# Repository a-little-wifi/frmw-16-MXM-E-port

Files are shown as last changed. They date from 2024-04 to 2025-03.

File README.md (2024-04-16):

# MXM GPU + Dell E-Port expansion card for 16" Framework laptop

This is a board meant to fit in the GPU expansion bay of the 16" Framework laptop. Its primary purpose is to add Dell E-port dock support, but since that requires display outputs, an MXM GPU slot is added as well.

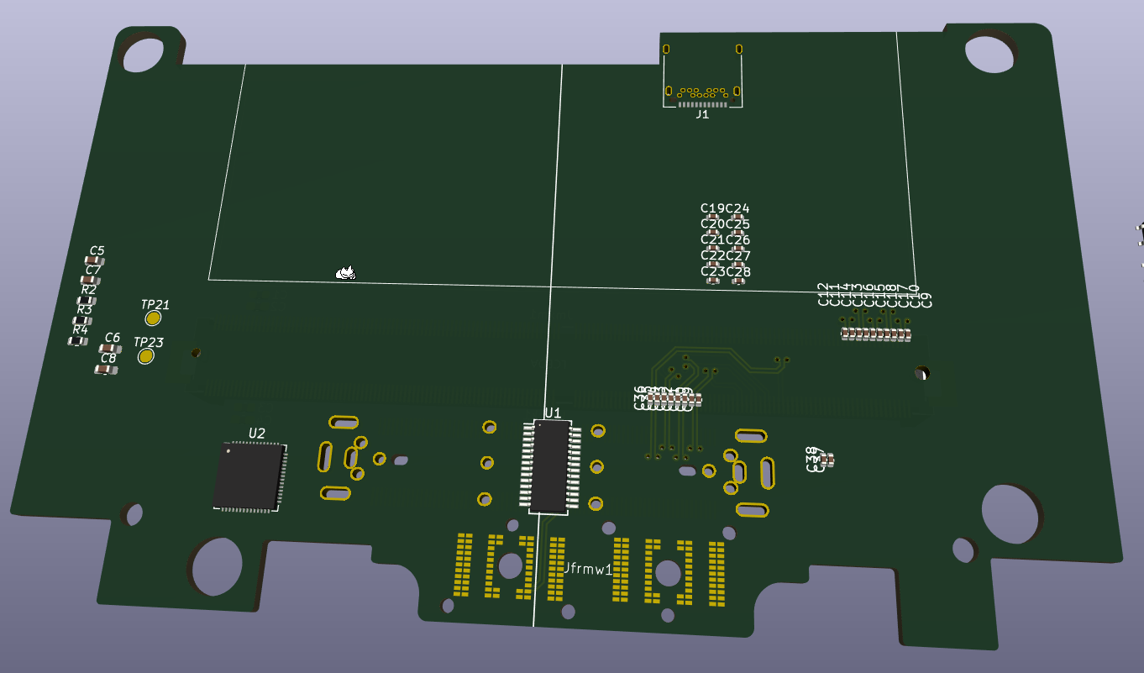
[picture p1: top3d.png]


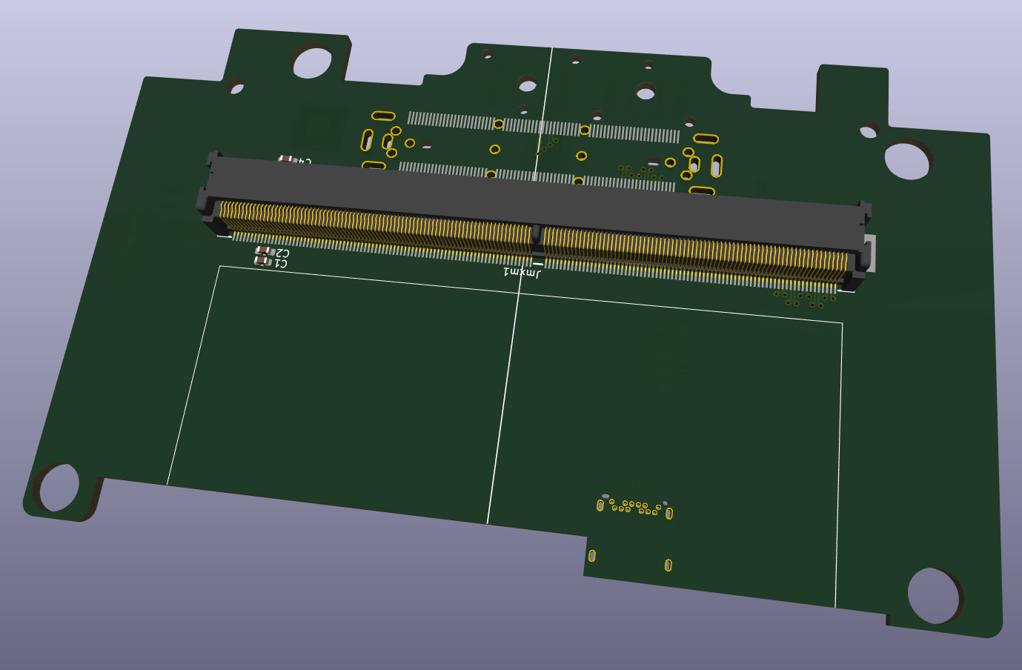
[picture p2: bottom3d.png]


This is a very unfinished project that I started when the 16" Framework laptop was announced, but I probably won't be working on it much anymore since I don't plan on actually buying the laptop. I'm putting it here for anyone who might be interested.

The intent was to use the RP2040 to deal with dock port interfaces such as PS/2, I2S audio, and whatever other control signals it needs to function.

MXM part is based on my work on another project: MXM Immobilizer, a PCIe to MXM adapter.

I've manually created the E-port dock connector footprint from the part datasheet: https://www.mouser.com/pdfdocs/JAEMB-0200-1E_WD2.pdf

Dell's E-port dock uses the JAE WD2 series dock connectors. Part numbers commonly mentioned in applicable schematics are:
* JAE_WD2F144WB5R400 (M4800)
* JAE_WD2F144WB1R300 (E6440)
* JAE_WD2F144WBHR500-DT (E7470)
* JAE_WD2F144WD3 (E4300)
* JAE_WD2F144WD4 (E4200)
* JAE_WD2F144WB3R300 (E4310)
* JAE_WD2F144WB7-DT (E7440)
* JAE_WD2F144WB1 (E6400)

Plus a Foxconn alternative used in some of the last models:
* FOX_QL01723-D265G1-8H (Precision 7510)

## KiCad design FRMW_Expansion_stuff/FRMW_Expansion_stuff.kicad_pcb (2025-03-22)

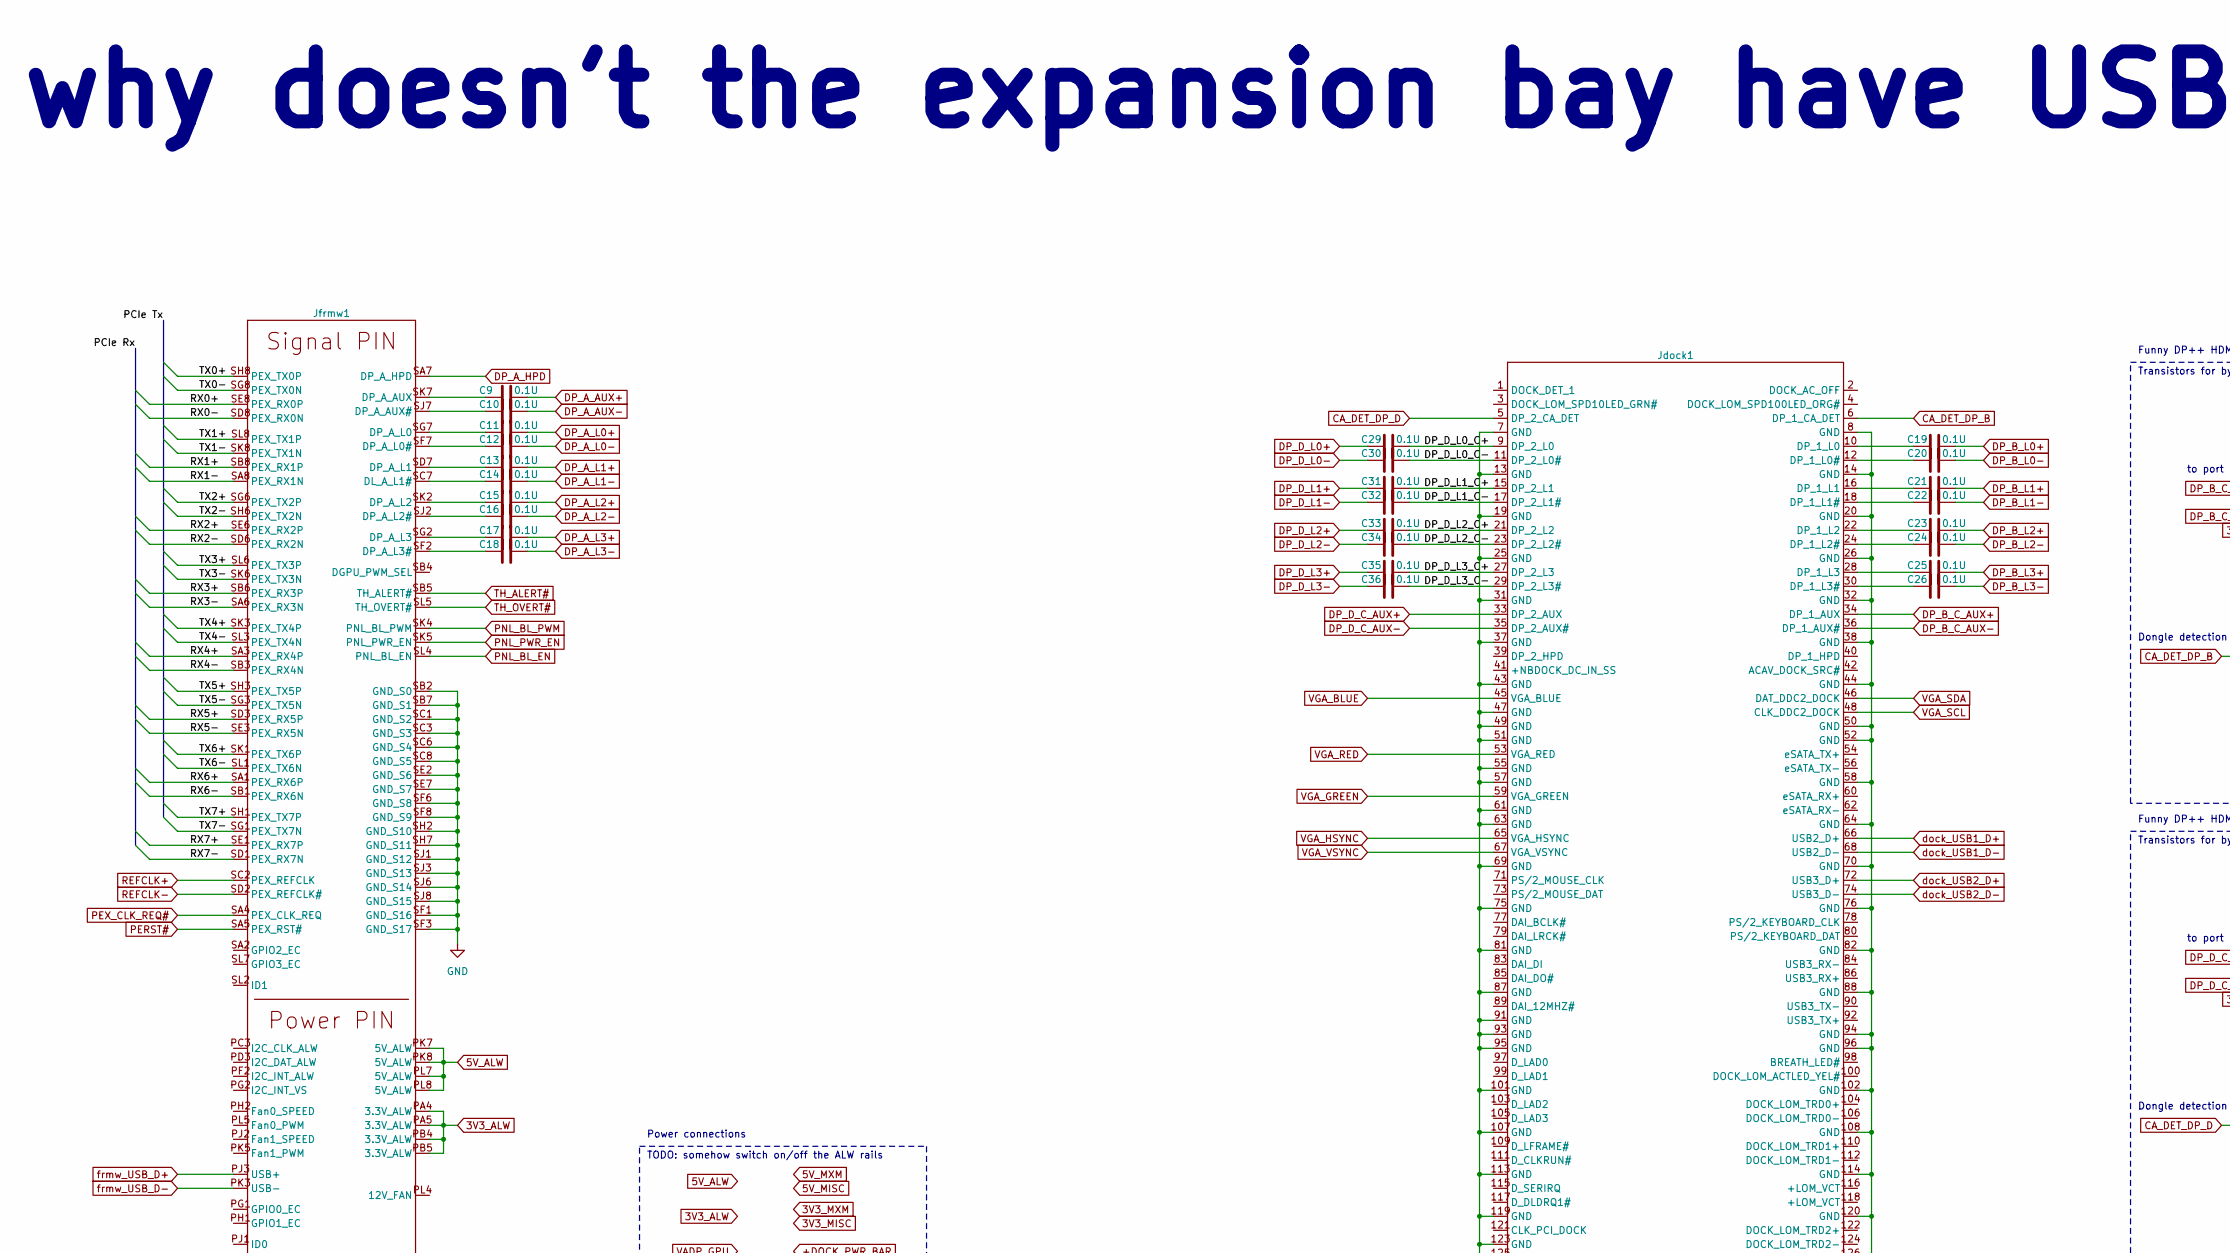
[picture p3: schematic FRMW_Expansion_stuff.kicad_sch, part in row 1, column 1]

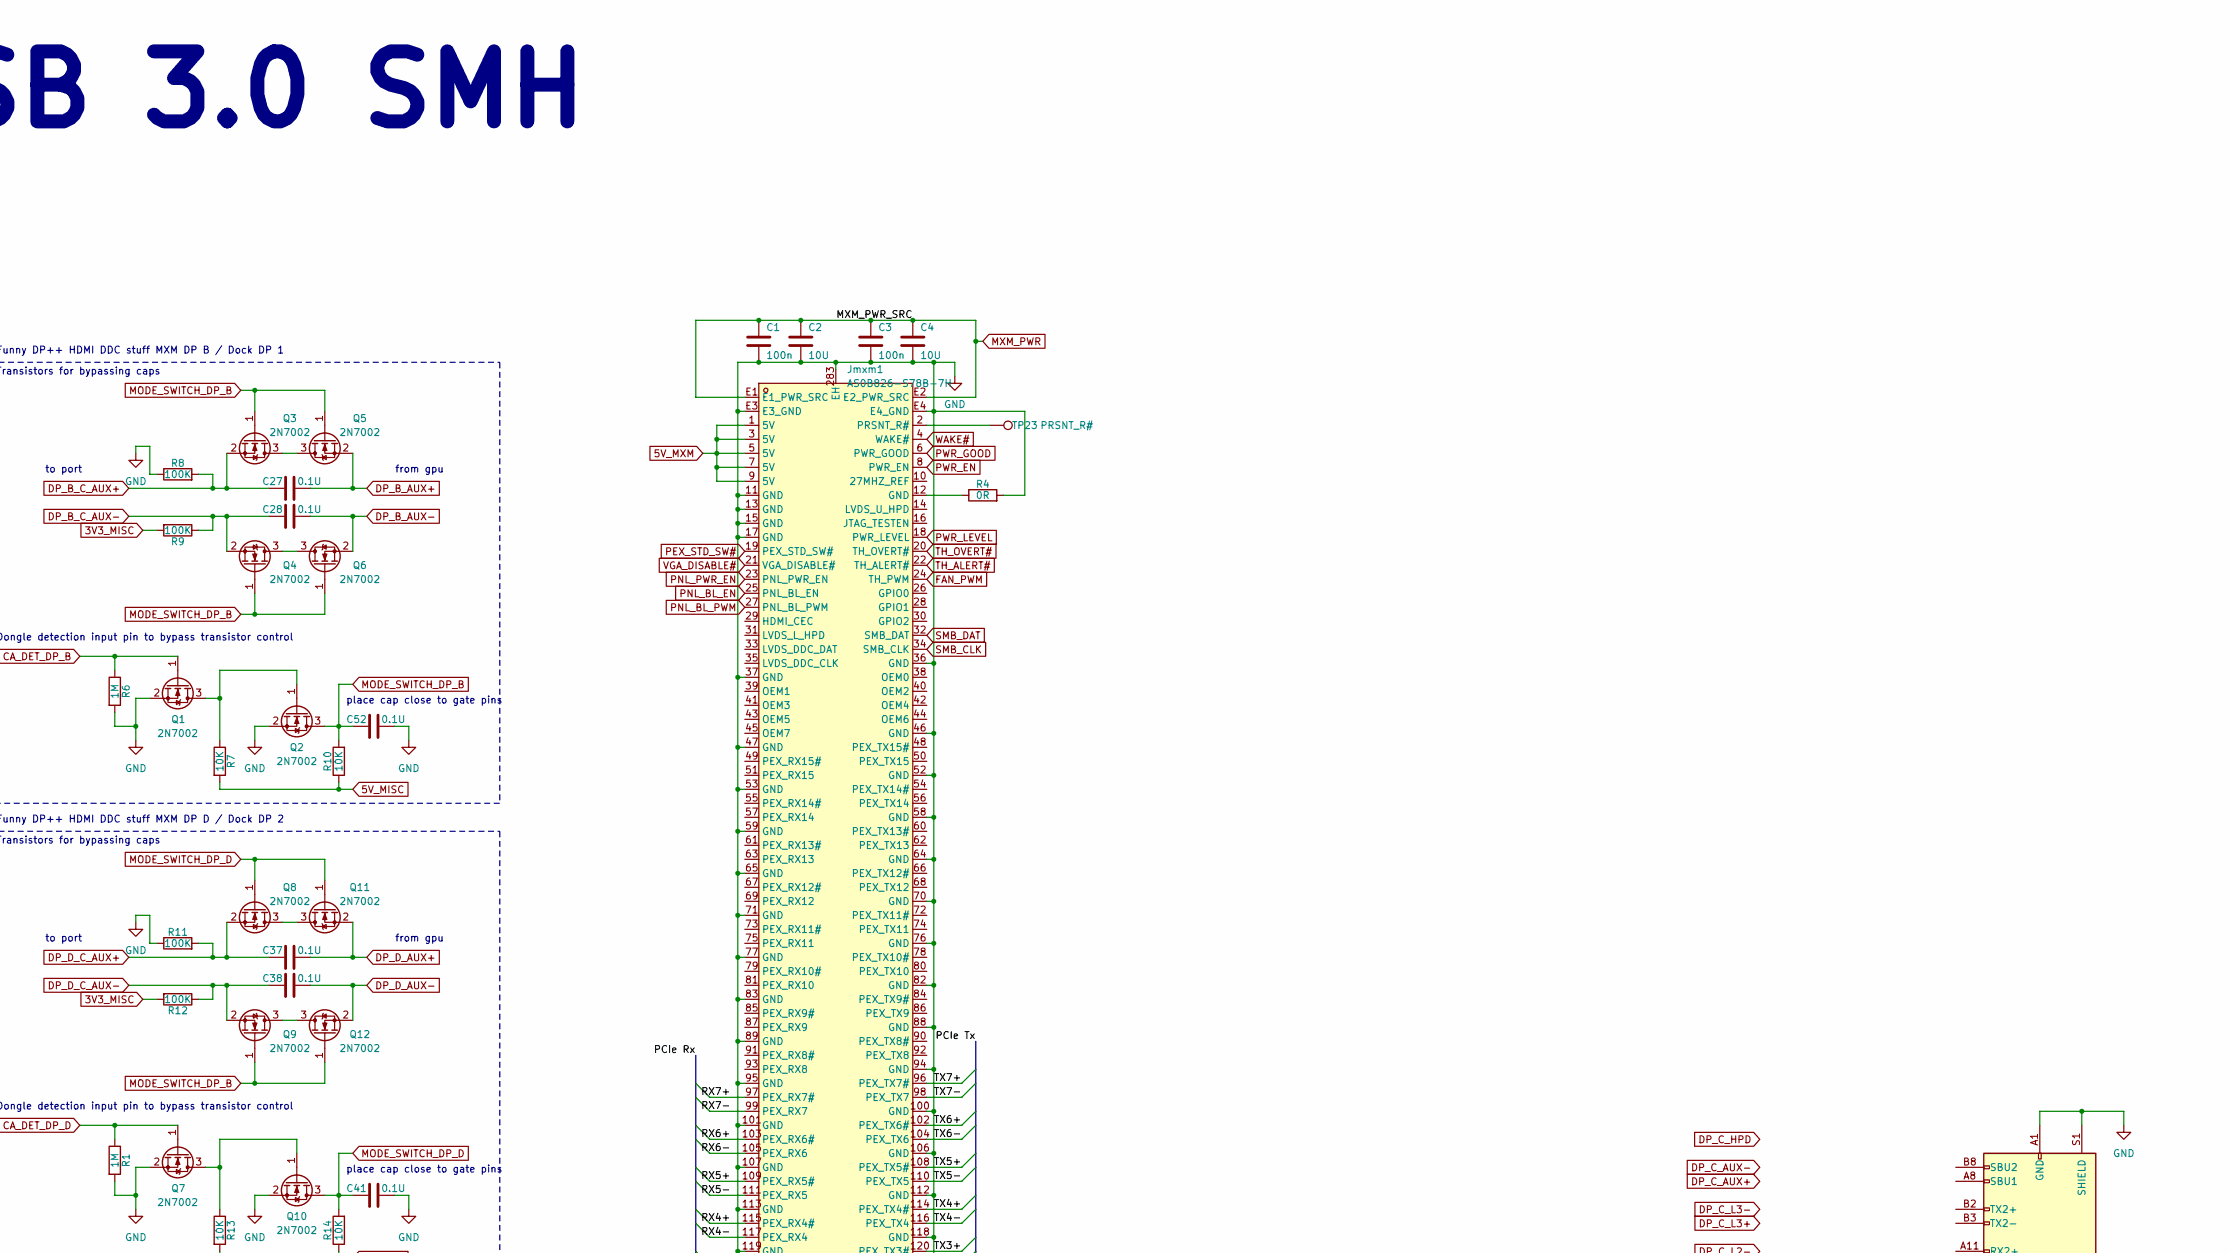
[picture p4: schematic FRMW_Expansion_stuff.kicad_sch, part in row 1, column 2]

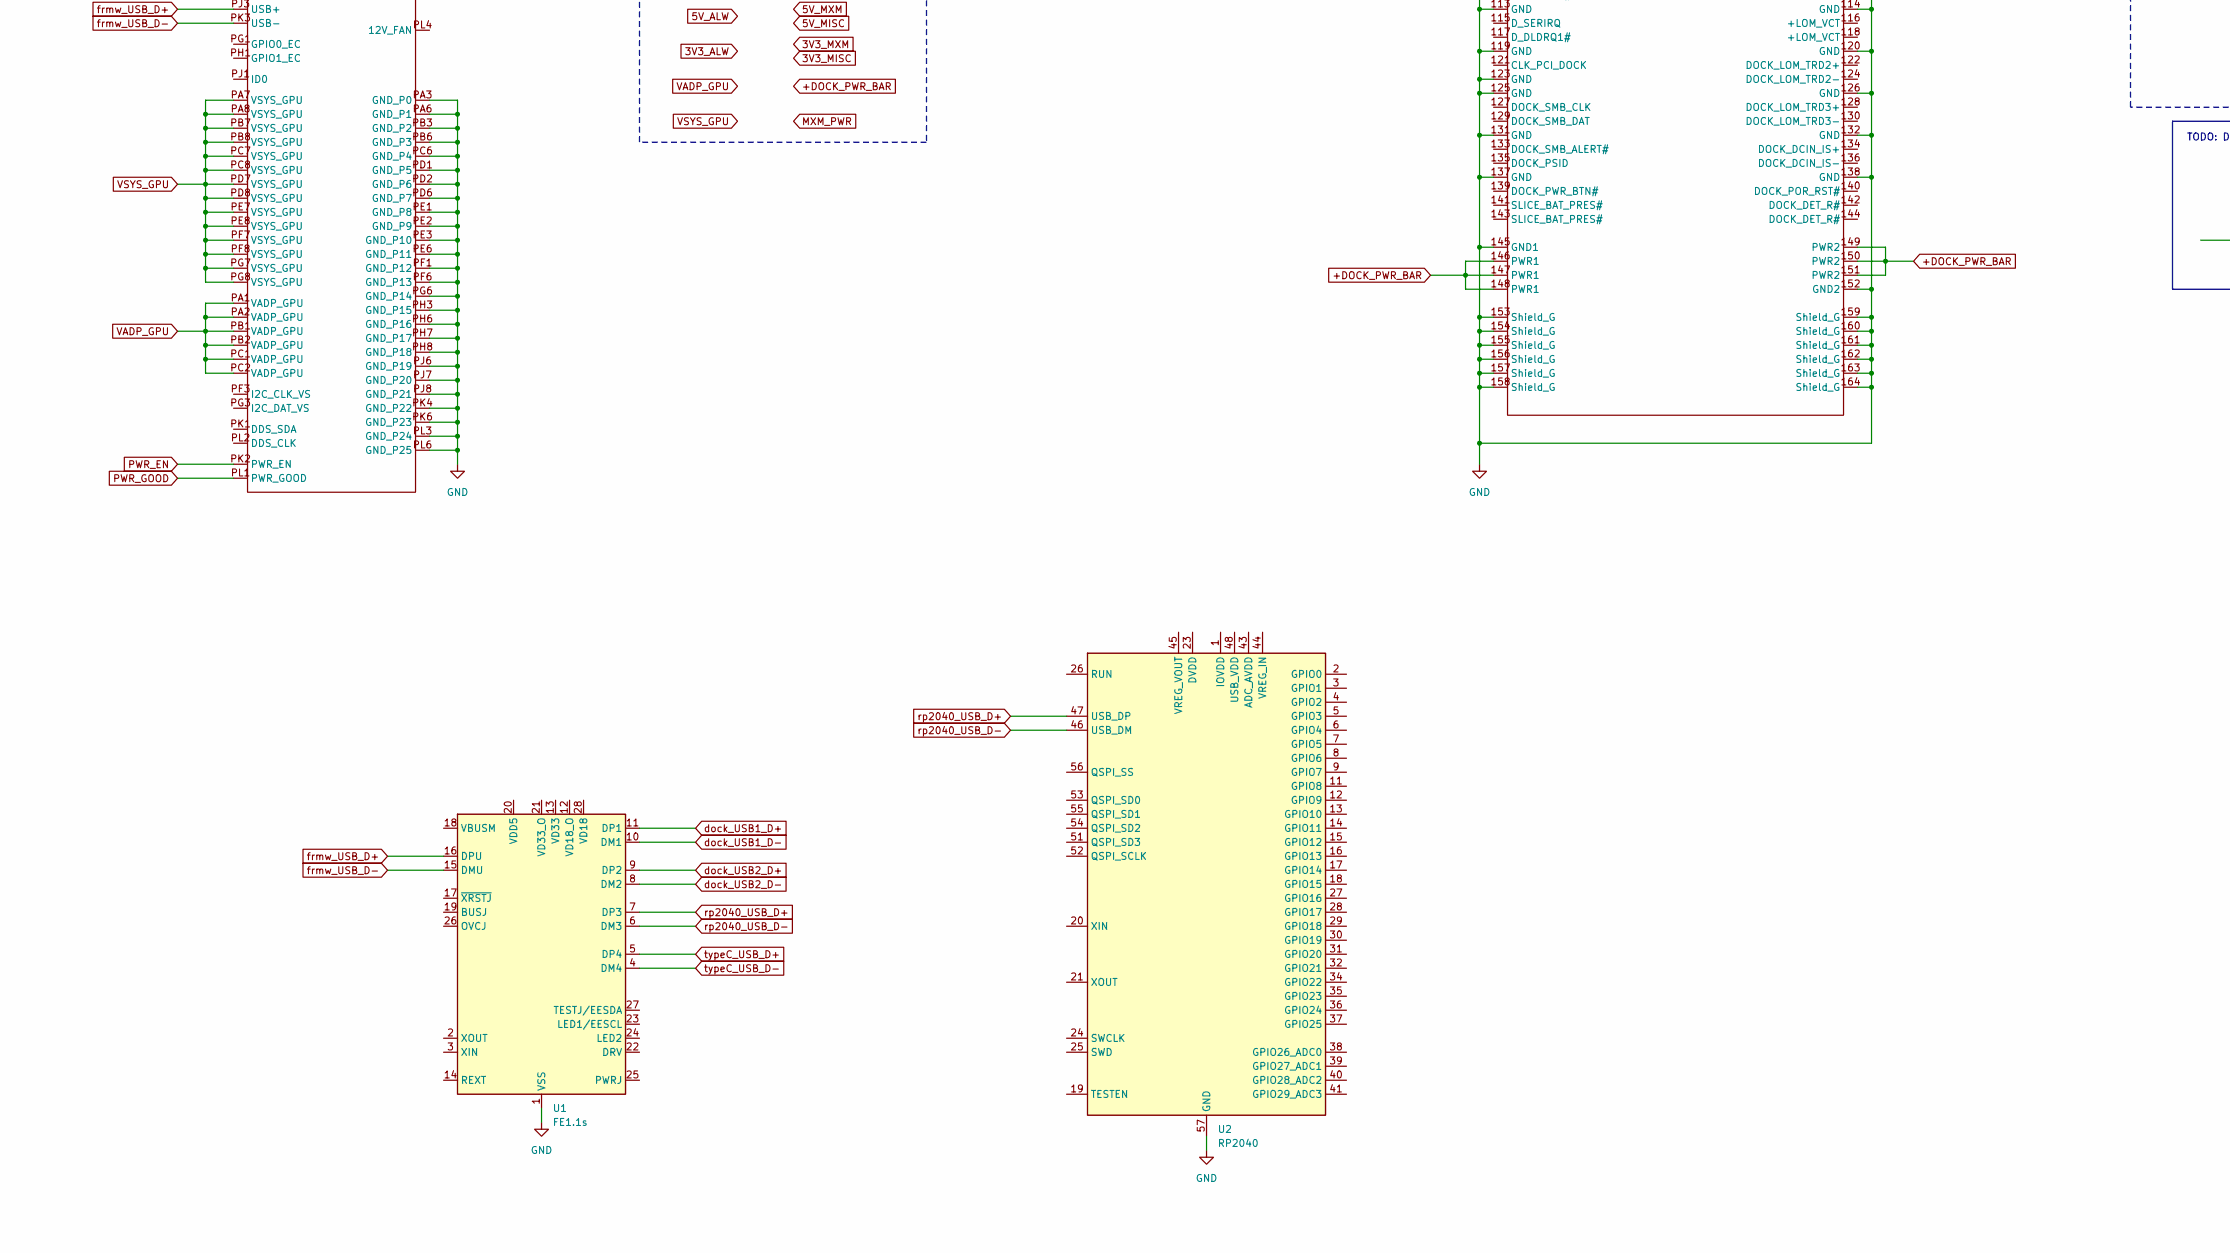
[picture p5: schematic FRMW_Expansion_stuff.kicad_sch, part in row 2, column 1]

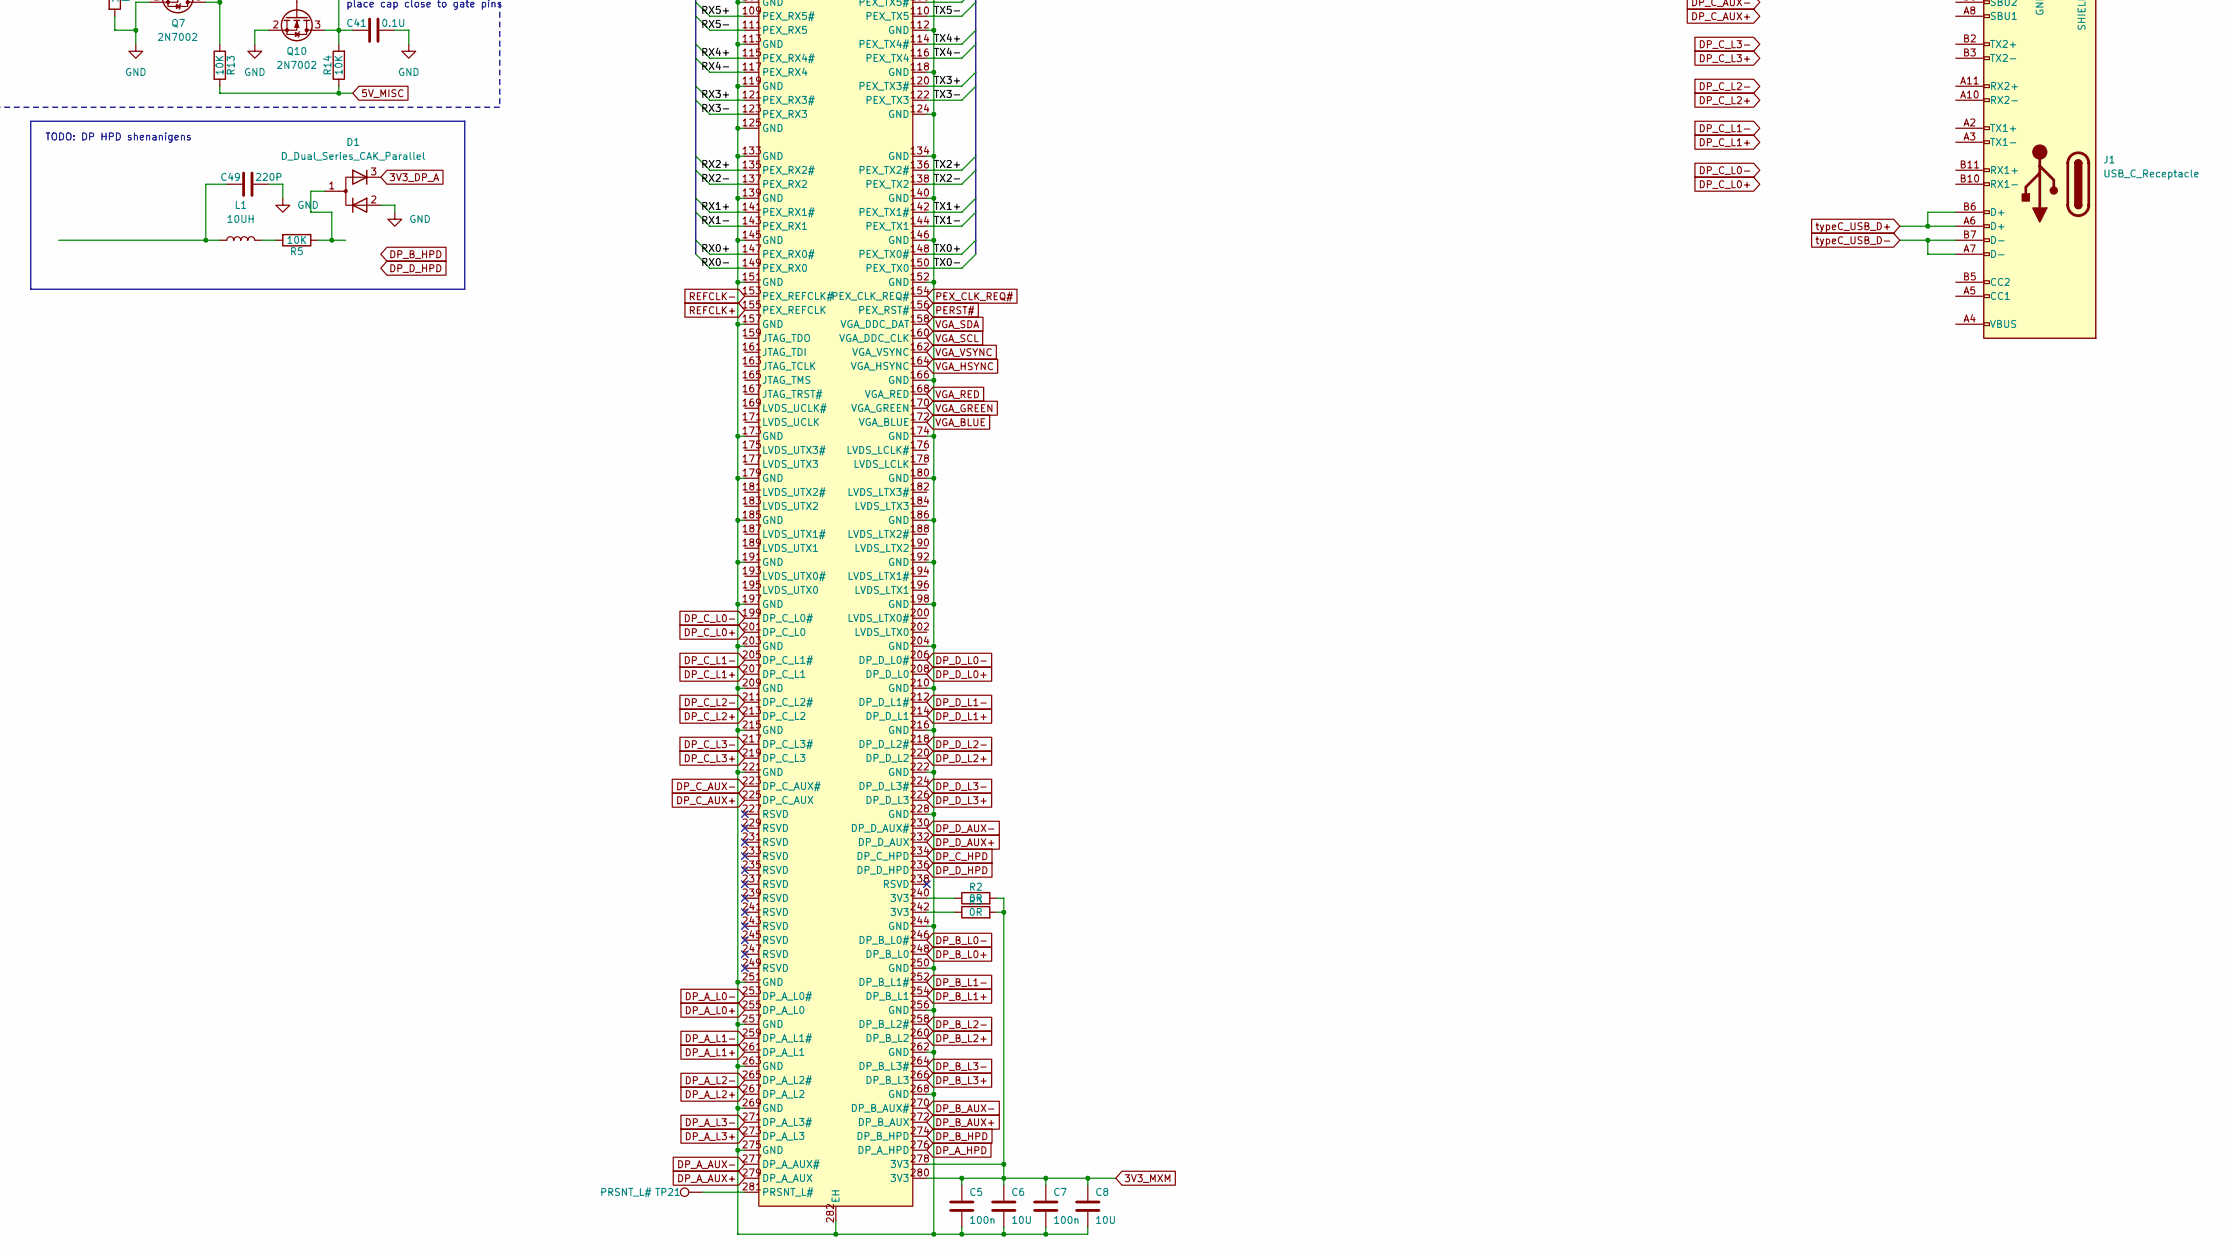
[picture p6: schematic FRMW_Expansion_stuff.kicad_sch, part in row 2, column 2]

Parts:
C1, C3, C5, C7: 100n; C_0603_1608Metric
C2, C4, C6, C8: 10U; C_0603_1608Metric_Pad1.08x0.95mm_HandSolder
C9, C10, C11, C12, C13, C14, C15, C16, C17, C18, C19, C20, C21, C22, C23, C24, C25, C26, C27, C28, C29, C30, C31, C32, C33, C34, C35, C36, C37, C38: 0.1U; C_0402_1005Metric
C41, C52: 0.1U; C_0603_1608Metric
C49: 220P; C_0603_1608Metric
D1: D_Dual_Series_CAK_Parallel; SOT-23
J1: USB_C_Receptacle; USB_C_Receptacle_Amphenol_12401548E4-2A
Jdock1: DellDock
Jfrmw1: Expansion_Bay_FXBeam
Jmxm1: AS0B826-S78B-7H; CONN-SMD_AS0B826-S78B-7H; LCSC Part C426232
L1: 10UH; L_0603_1608Metric_Pad1.05x0.95mm_HandSolder
Q1, Q2, Q3, Q4, Q5, Q6, Q7, Q8, Q9, Q10, Q11, Q12: 2N7002; SOT-23
R1, R6: 1M; R_0603_1608Metric
R2, R3, R4: 0R; R_0603_1608Metric
R5, R7, R10, R13, R14: 10K; R_0603_1608Metric
R8, R9, R11, R12: 100K; R_0603_1608Metric
TP21: PRSNT_L#; TestPoint_Pad_D1.5mm
TP23: PRSNT_R#; TestPoint_Pad_D1.5mm
U1: FE1.1s; SSOP-28_3.9x9.9mm_P0.635mm
U2: RP2040; QFN-56-1EP_7x7mm_P0.4mm_EP3.2x3.2mm

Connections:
3V3_ALW: Jfrmw1.PA4 (3.3V_ALW), Jfrmw1.PA5 (3.3V_ALW), Jfrmw1.PB4 (3.3V_ALW), Jfrmw1.PB5 (3.3V_ALW)
3V3_DP_A: D1.3 (K)
3V3_MISC: R9.2, R12.2
3V3_MXM: C5.1, C6.1, C7.1, C8.1, Jmxm1.278 (3V3), Jmxm1.280 (3V3), R2.2, R3.2
5V_ALW: Jfrmw1.PK7 (5V_ALW), Jfrmw1.PK8 (5V_ALW), Jfrmw1.PL7 (5V_ALW), Jfrmw1.PL8 (5V_ALW)
5V_MISC: R7.2, R10.1, R13.2, R14.1
5V_MXM: Jmxm1.1 (5V), Jmxm1.3 (5V), Jmxm1.5 (5V), Jmxm1.7 (5V), Jmxm1.9 (5V)
+DOCK_PWR_BAR: Jdock1.146 (PWR1), Jdock1.147 (PWR1), Jdock1.148 (PWR1), Jdock1.149 (PWR2), Jdock1.150 (PWR2), Jdock1.151 (PWR2)
/DP_D_L0_C+: C29.1, Jdock1.9 (DP_2_L0)
/DP_D_L0_C-: C30.1, Jdock1.11 (DP_2_L0#)
/DP_D_L1_C+: C31.1, Jdock1.15 (DP_2_L1)
/DP_D_L1_C-: C32.1, Jdock1.17 (DP_2_L1#)
/DP_D_L2_C+: C33.1, Jdock1.21 (DP_2_L2)
/DP_D_L2_C-: C34.1, Jdock1.23 (DP_2_L2#)
/DP_D_L3_C+: C35.1, Jdock1.27 (DP_2_L3)
/DP_D_L3_C-: C36.1, Jdock1.29 (DP_2_L3#)
/RX0+: Jfrmw1.SE8 (PEX_RX0P), Jmxm1.147 (PEX_RX0#)
/RX0-: Jfrmw1.SD8 (PEX_RX0N), Jmxm1.149 (PEX_RX0)
/RX1+: Jfrmw1.SB8 (PEX_RX1P), Jmxm1.141 (PEX_RX1#)
/RX1-: Jfrmw1.SA8 (PEX_RX1N), Jmxm1.143 (PEX_RX1)
/RX2+: Jfrmw1.SE6 (PEX_RX2P), Jmxm1.135 (PEX_RX2#)
/RX2-: Jfrmw1.SD6 (PEX_RX2N), Jmxm1.137 (PEX_RX2)
/RX3+: Jfrmw1.SB6 (PEX_RX3P), Jmxm1.121 (PEX_RX3#)
/RX3-: Jfrmw1.SA6 (PEX_RX3N), Jmxm1.123 (PEX_RX3)
/RX4+: Jfrmw1.SA3 (PEX_RX4P), Jmxm1.115 (PEX_RX4#)
/RX4-: Jfrmw1.SB3 (PEX_RX4N), Jmxm1.117 (PEX_RX4)
/RX5+: Jfrmw1.SD3 (PEX_RX5P), Jmxm1.109 (PEX_RX5#)
/RX5-: Jfrmw1.SE3 (PEX_RX5N), Jmxm1.111 (PEX_RX5)
/RX6+: Jfrmw1.SA1 (PEX_RX6P), Jmxm1.103 (PEX_RX6#)
/RX6-: Jfrmw1.SB1 (PEX_RX6N), Jmxm1.105 (PEX_RX6)
/RX7+: Jfrmw1.SE1 (PEX_RX7P), Jmxm1.97 (PEX_RX7#)
/RX7-: Jfrmw1.SD1 (PEX_RX7N), Jmxm1.99 (PEX_RX7)
/TX0+: Jfrmw1.SH8 (PEX_TX0P), Jmxm1.148 (PEX_TX0#)
/TX0-: Jfrmw1.SG8 (PEX_TX0N), Jmxm1.150 (PEX_TX0)
/TX1+: Jfrmw1.SL8 (PEX_TX1P), Jmxm1.142 (PEX_TX1#)
/TX1-: Jfrmw1.SK8 (PEX_TX1N), Jmxm1.144 (PEX_TX1)
/TX2+: Jfrmw1.SG6 (PEX_TX2P), Jmxm1.136 (PEX_TX2#)
/TX2-: Jfrmw1.SH6 (PEX_TX2N), Jmxm1.138 (PEX_TX2)
/TX3+: Jfrmw1.SL6 (PEX_TX3P), Jmxm1.120 (PEX_TX3#)
/TX3-: Jfrmw1.SK6 (PEX_TX3N), Jmxm1.122 (PEX_TX3)
/TX4+: Jfrmw1.SK3 (PEX_TX4P), Jmxm1.114 (PEX_TX4#)
/TX4-: Jfrmw1.SL3 (PEX_TX4N), Jmxm1.116 (PEX_TX4)
/TX5+: Jfrmw1.SH3 (PEX_TX5P), Jmxm1.108 (PEX_TX5#)
/TX5-: Jfrmw1.SG3 (PEX_TX5N), Jmxm1.110 (PEX_TX5)
/TX6+: Jfrmw1.SK1 (PEX_TX6P), Jmxm1.102 (PEX_TX6#)
/TX6-: Jfrmw1.SL1 (PEX_TX6N), Jmxm1.104 (PEX_TX6)
/TX7+: Jfrmw1.SH1 (PEX_TX7P), Jmxm1.96 (PEX_TX7#)
/TX7-: Jfrmw1.SG1 (PEX_TX7N), Jmxm1.98 (PEX_TX7)
CA_DET_DP_B: Jdock1.6 (DP_1_CA_DET), Q1.1 (G), R6.1
CA_DET_DP_D: Jdock1.5 (DP_2_CA_DET), Q7.1 (G), R1.1
DP_A_AUX+: C9.1, Jmxm1.279 (DP_A_AUX)
DP_A_AUX-: C10.1, Jmxm1.277 (DP_A_AUX#)
DP_A_HPD: Jfrmw1.SA7 (DP_A_HPD), Jmxm1.276 (DP_A_HPD)
DP_A_L0+: C11.1, Jmxm1.255 (DP_A_L0)
DP_A_L0-: C12.1, Jmxm1.253 (DP_A_L0#)
DP_A_L1+: C13.1, Jmxm1.261 (DP_A_L1)
DP_A_L1-: C14.1, Jmxm1.259 (DP_A_L1#)
DP_A_L2+: C15.1, Jmxm1.267 (DP_A_L2)
DP_A_L2-: C16.1, Jmxm1.265 (DP_A_L2#)
DP_A_L3+: C17.1, Jmxm1.273 (DP_A_L3)
DP_A_L3-: C18.1, Jmxm1.271 (DP_A_L3#)
DP_B_AUX+: C27.1, Jmxm1.272 (DP_B_AUX), Q5.2 (S)
DP_B_AUX-: C28.1, Jmxm1.270 (DP_B_AUX#), Q6.2 (S)
DP_B_C_AUX+: C27.2, Jdock1.34 (DP_1_AUX), Q3.2 (S), R8.2
DP_B_C_AUX-: C28.2, Jdock1.36 (DP_1_AUX#), Q4.2 (S), R9.1
DP_B_HPD: Jmxm1.274 (DP_B_HPD)
DP_B_L0+: C19.1, Jmxm1.248 (DP_B_L0)
DP_B_L0-: C20.1, Jmxm1.246 (DP_B_L0#)
DP_B_L1+: C21.1, Jmxm1.254 (DP_B_L1)
DP_B_L1-: C22.1, Jmxm1.252 (DP_B_L1#)
DP_B_L2+: C23.1, Jmxm1.260 (DP_B_L2)
DP_B_L2-: C24.1, Jmxm1.258 (DP_B_L2#)
DP_B_L3+: C25.1, Jmxm1.266 (DP_B_L3)
DP_B_L3-: C26.1, Jmxm1.264 (DP_B_L3#)
DP_C_AUX+: Jmxm1.225 (DP_C_AUX)
DP_C_AUX-: Jmxm1.223 (DP_C_AUX#)
DP_C_HPD: Jmxm1.234 (DP_C_HPD)
DP_C_L0+: Jmxm1.201 (DP_C_L0)
DP_C_L0-: Jmxm1.199 (DP_C_L0#)
DP_C_L1+: Jmxm1.207 (DP_C_L1)
DP_C_L1-: Jmxm1.205 (DP_C_L1#)
DP_C_L2+: Jmxm1.213 (DP_C_L2)
DP_C_L2-: Jmxm1.211 (DP_C_L2#)
DP_C_L3+: Jmxm1.219 (DP_C_L3)
DP_C_L3-: Jmxm1.217 (DP_C_L3#)
DP_D_AUX+: C37.1, Jmxm1.232 (DP_D_AUX), Q11.2 (S)
DP_D_AUX-: C38.1, Jmxm1.230 (DP_D_AUX#), Q12.2 (S)
DP_D_C_AUX+: C37.2, Jdock1.33 (DP_2_AUX), Q8.2 (S), R11.2
DP_D_C_AUX-: C38.2, Jdock1.35 (DP_2_AUX#), Q9.2 (S), R12.1
DP_D_HPD: Jmxm1.236 (DP_D_HPD)
DP_D_L0+: C29.2, Jmxm1.208 (DP_D_L0)
DP_D_L0-: C30.2, Jmxm1.206 (DP_D_L0#)
DP_D_L1+: C31.2, Jmxm1.214 (DP_D_L1)
DP_D_L1-: C32.2, Jmxm1.212 (DP_D_L1#)
DP_D_L2+: C33.2, Jmxm1.220 (DP_D_L2)
DP_D_L2-: C34.2, Jmxm1.218 (DP_D_L2#)
DP_D_L3+: C35.2, Jmxm1.226 (DP_D_L3)
DP_D_L3-: C36.2, Jmxm1.224 (DP_D_L3#)
FAN_PWM: Jmxm1.24 (TH_PWM)
GND: C1.2, C2.2, C3.2, C4.2, C5.2, C6.2, C7.2, C8.2, C41.1, C49.1, C52.1, D1.2 (K), J1.A1 (GND), J1.A12 (GND), J1.B1 (GND), J1.B12 (GND), J1.S1 (SHIELD), Jdock1.7 (GND), Jdock1.8 (GND), Jdock1.13 (GND), Jdock1.14 (GND), Jdock1.19 (GND), Jdock1.20 (GND), Jdock1.25 (GND), Jdock1.26 (GND), Jdock1.31 (GND), Jdock1.32 (GND), Jdock1.37 (GND), Jdock1.38 (GND), Jdock1.43 (GND), Jdock1.44 (GND), Jdock1.47 (GND), Jdock1.49 (GND), Jdock1.50 (GND), Jdock1.51 (GND), Jdock1.52 (GND), Jdock1.55 (GND), Jdock1.57 (GND), Jdock1.58 (GND), Jdock1.61 (GND), Jdock1.63 (GND), Jdock1.64 (GND), Jdock1.69 (GND), Jdock1.70 (GND), Jdock1.75 (GND), Jdock1.76 (GND), Jdock1.81 (GND), Jdock1.82 (GND), Jdock1.87 (GND), Jdock1.88 (GND), Jdock1.91 (GND), Jdock1.93 (GND), Jdock1.94 (GND), Jdock1.95 (GND), Jdock1.96 (GND), Jdock1.101 (GND), Jdock1.102 (GND), Jdock1.107 (GND), Jdock1.108 (GND), Jdock1.113 (GND), Jdock1.114 (GND), Jdock1.119 (GND), Jdock1.120 (GND), Jdock1.123 (GND), Jdock1.125 (GND), Jdock1.126 (GND), Jdock1.131 (GND), Jdock1.132 (GND), Jdock1.137 (GND), Jdock1.138 (GND), Jdock1.145 (GND1), Jdock1.152 (GND2), Jdock1.153 (Shield_G), Jdock1.154 (Shield_G), Jdock1.155 (Shield_G), Jdock1.156 (Shield_G), Jdock1.157 (Shield_G), Jdock1.158 (Shield_G), Jdock1.159 (Shield_G), Jdock1.160 (Shield_G), Jdock1.161 (Shield_G), Jdock1.162 (Shield_G), Jdock1.163 (Shield_G), Jdock1.164 (Shield_G), Jfrmw1.PA3 (GND_P0), Jfrmw1.PA6 (GND_P1), Jfrmw1.PB3 (GND_P2), Jfrmw1.PB6 (GND_P3), Jfrmw1.PC6 (GND_P4), Jfrmw1.PD1 (GND_P5), Jfrmw1.PD2 (GND_P6), Jfrmw1.PD6 (GND_P7), Jfrmw1.PE1 (GND_P8), Jfrmw1.PE2 (GND_P9), Jfrmw1.PE3 (GND_P10), Jfrmw1.PE6 (GND_P11), Jfrmw1.PF1 (GND_P12), Jfrmw1.PF6 (GND_P13), Jfrmw1.PG6 (GND_P14), Jfrmw1.PH3 (GND_P15), Jfrmw1.PH6 (GND_P16), Jfrmw1.PH7 (GND_P17), Jfrmw1.PH8 (GND_P18), Jfrmw1.PJ6 (GND_P19), Jfrmw1.PJ7 (GND_P20), Jfrmw1.PJ8 (GND_P21), Jfrmw1.PK4 (GND_P22), Jfrmw1.PK6 (GND_P23), Jfrmw1.PL3 (GND_P24), Jfrmw1.PL6 (GND_P25), Jfrmw1.SB2 (GND_S0), Jfrmw1.SB7 (GND_S1), Jfrmw1.SC1 (GND_S2), Jfrmw1.SC3 (GND_S3), Jfrmw1.SC6 (GND_S4), Jfrmw1.SC8 (GND_S5), Jfrmw1.SE2 (GND_S6), Jfrmw1.SE7 (GND_S7), Jfrmw1.SF1 (GND_S16), Jfrmw1.SF3 (GND_S17), Jfrmw1.SF6 (GND_S8), Jfrmw1.SF8 (GND_S9), Jfrmw1.SH2 (GND_S10), Jfrmw1.SH7 (GND_S11), Jfrmw1.SJ1 (GND_S12), Jfrmw1.SJ3 (GND_S13), Jfrmw1.SJ6 (GND_S14), Jfrmw1.SJ8 (GND_S15), Jmxm1.11 (GND), Jmxm1.13 (GND), Jmxm1.15 (GND), Jmxm1.17 (GND), Jmxm1.36 (GND), Jmxm1.37 (GND), Jmxm1.46 (GND), Jmxm1.47 (GND), Jmxm1.52 (GND), Jmxm1.53 (GND), Jmxm1.58 (GND), Jmxm1.59 (GND), Jmxm1.64 (GND), Jmxm1.65 (GND), Jmxm1.70 (GND), Jmxm1.71 (GND), Jmxm1.76 (GND), Jmxm1.77 (GND), Jmxm1.82 (GND), Jmxm1.83 (GND), Jmxm1.88 (GND), Jmxm1.89 (GND), Jmxm1.94 (GND), Jmxm1.95 (GND), Jmxm1.100 (GND), Jmxm1.101 (GND), Jmxm1.106 (GND), Jmxm1.107 (GND), Jmxm1.112 (GND), Jmxm1.113 (GND), Jmxm1.118 (GND), Jmxm1.119 (GND), Jmxm1.124 (GND), Jmxm1.125 (GND), Jmxm1.133 (GND), Jmxm1.134 (GND), Jmxm1.139 (GND), Jmxm1.140 (GND), Jmxm1.145 (GND), Jmxm1.146 (GND), Jmxm1.151 (GND), Jmxm1.152 (GND), Jmxm1.157 (GND), Jmxm1.166 (GND), Jmxm1.173 (GND), Jmxm1.174 (GND), Jmxm1.179 (GND), Jmxm1.180 (GND), Jmxm1.185 (GND), Jmxm1.186 (GND), Jmxm1.191 (GND), Jmxm1.192 (GND), Jmxm1.197 (GND), Jmxm1.198 (GND), Jmxm1.203 (GND), Jmxm1.204 (GND), Jmxm1.209 (GND), Jmxm1.210 (GND), Jmxm1.215 (GND), Jmxm1.216 (GND), Jmxm1.221 (GND), Jmxm1.222 (GND), Jmxm1.228 (GND), Jmxm1.244 (GND), Jmxm1.250 (GND), Jmxm1.251 (GND), Jmxm1.256 (GND), Jmxm1.257 (GND), Jmxm1.262 (GND), Jmxm1.263 (GND), Jmxm1.268 (GND), Jmxm1.269 (GND), Jmxm1.275 (GND), Jmxm1.282 (EH), Jmxm1.283 (EH), Jmxm1.E3 (E3_GND), Jmxm1.E4 (E4_GND), Q1.2 (S), Q2.2 (S), Q7.2 (S), Q10.2 (S), R1.2, R4.2, R6.2, R8.1, R11.1, U1.1 (VSS), U2.57 (GND)
MODE_SWITCH_DP_B: C52.2, Q2.3 (D), Q3.1 (G), Q4.1 (G), Q5.1 (G), Q6.1 (G), Q9.1 (G), Q12.1 (G), R10.2
MODE_SWITCH_DP_D: C41.2, Q8.1 (G), Q10.3 (D), Q11.1 (G), R14.2
MXM_PWR: C1.1, C2.1, C3.1, C4.1, Jmxm1.E1 (E1_PWR_SRC), Jmxm1.E2 (E2_PWR_SRC)
unnamed: C49.2, L1.1
unnamed: D1.1 (A), R5.1
unnamed: J1.A4 (VBUS), J1.A9 (VBUS), J1.B4 (VBUS), J1.B9 (VBUS)
unnamed: C20.2, Jdock1.12 (DP_1_L0#)
unnamed: C19.2, Jdock1.10 (DP_1_L0)
unnamed: C22.2, Jdock1.18 (DP_1_L1#)
unnamed: C21.2, Jdock1.16 (DP_1_L1)
unnamed: C24.2, Jdock1.24 (DP_1_L2#)
unnamed: C23.2, Jdock1.22 (DP_1_L2)
unnamed: C26.2, Jdock1.30 (DP_1_L3#)
unnamed: C25.2, Jdock1.28 (DP_1_L3)
unnamed: C14.2, Jfrmw1.SC7 (DL_A_L1#)
unnamed: C10.2, Jfrmw1.SJ7 (DP_A_AUX#)
unnamed: C9.2, Jfrmw1.SK7 (DP_A_AUX)
unnamed: C12.2, Jfrmw1.SF7 (DP_A_L0#)
unnamed: C11.2, Jfrmw1.SG7 (DP_A_L0)
unnamed: C13.2, Jfrmw1.SD7 (DP_A_L1)
unnamed: C16.2, Jfrmw1.SJ2 (DP_A_L2#)
unnamed: C15.2, Jfrmw1.SK2 (DP_A_L2)
unnamed: C18.2, Jfrmw1.SF2 (DP_A_L3#)
unnamed: C17.2, Jfrmw1.SG2 (DP_A_L3)
unnamed: Jmxm1.240 (3V3), R2.1
unnamed: Jmxm1.242 (3V3), R3.1
unnamed: Jmxm1.12 (GND), R4.1
unnamed: Jmxm1.281 (PRSNT_L#), TP21.1
unnamed: Jmxm1.2 (PRSNT_R#), TP23.1
unnamed: L1.2, R5.2
unnamed: Q1.3 (D), Q2.1 (G), R7.1
unnamed: Q3.3 (D), Q5.3 (D)
unnamed: Q4.3 (D), Q6.3 (D)
unnamed: Q7.3 (D), Q10.1 (G), R13.1
unnamed: Q8.3 (D), Q11.3 (D)
unnamed: Q9.3 (D), Q12.3 (D)
unnamed: U2.23 (DVDD), U2.50 (DVDD)
unnamed: U2.1 (IOVDD), U2.10 (IOVDD), U2.22 (IOVDD), U2.33 (IOVDD), U2.42 (IOVDD), U2.49 (IOVDD)
PERST#: Jfrmw1.SA5 (PEX_RST#), Jmxm1.156 (PEX_RST#)
PEX_CLK_REQ#: Jfrmw1.SA4 (PEX_CLK_REQ), Jmxm1.154 (PEX_CLK_REQ#)
PEX_STD_SW#: Jmxm1.19 (PEX_STD_SW#)
PNL_BL_EN: Jfrmw1.SL4 (PNL_BL_EN), Jmxm1.25 (PNL_BL_EN)
PNL_BL_PWM: Jfrmw1.SK4 (PNL_BL_PWM), Jmxm1.27 (PNL_BL_PWM)
PNL_PWR_EN: Jfrmw1.SK5 (PNL_PWR_EN), Jmxm1.23 (PNL_PWR_EN)
PWR_EN: Jfrmw1.PK2 (PWR_EN), Jmxm1.8 (PWR_EN)
PWR_GOOD: Jfrmw1.PL1 (PWR_GOOD), Jmxm1.6 (PWR_GOOD)
PWR_LEVEL: Jmxm1.18 (PWR_LEVEL)
REFCLK+: Jfrmw1.SC2 (PEX_REFCLK), Jmxm1.155 (PEX_REFCLK)
REFCLK-: Jfrmw1.SD2 (PEX_REFCLK#), Jmxm1.153 (PEX_REFCLK#)
SMB_CLK: Jmxm1.34 (SMB_CLK)
SMB_DAT: Jmxm1.32 (SMB_DAT)
TH_ALERT#: Jfrmw1.SB5 (TH_ALERT#), Jmxm1.22 (TH_ALERT#)
TH_OVERT#: Jfrmw1.SL5 (TH_OVERT#), Jmxm1.20 (TH_OVERT#)
VADP_GPU: Jfrmw1.PA1 (VADP_GPU), Jfrmw1.PA2 (VADP_GPU), Jfrmw1.PB1 (VADP_GPU), Jfrmw1.PB2 (VADP_GPU), Jfrmw1.PC1 (VADP_GPU), Jfrmw1.PC2 (VADP_GPU)
VGA_BLUE: Jdock1.45 (VGA_BLUE), Jmxm1.172 (VGA_BLUE)
VGA_DISABLE#: Jmxm1.21 (VGA_DISABLE#)
VGA_GREEN: Jdock1.59 (VGA_GREEN), Jmxm1.170 (VGA_GREEN)
VGA_HSYNC: Jdock1.65 (VGA_HSYNC), Jmxm1.164 (VGA_HSYNC)
VGA_RED: Jdock1.53 (VGA_RED), Jmxm1.168 (VGA_RED)
VGA_SCL: Jdock1.48 (CLK_DDC2_DOCK), Jmxm1.160 (VGA_DDC_CLK)
VGA_SDA: Jdock1.46 (DAT_DDC2_DOCK), Jmxm1.158 (VGA_DDC_DAT)
VGA_VSYNC: Jdock1.67 (VGA_VSYNC), Jmxm1.162 (VGA_VSYNC)
VSYS_GPU: Jfrmw1.PA7 (VSYS_GPU), Jfrmw1.PA8 (VSYS_GPU), Jfrmw1.PB7 (VSYS_GPU), Jfrmw1.PB8 (VSYS_GPU), Jfrmw1.PC7 (VSYS_GPU), Jfrmw1.PC8 (VSYS_GPU), Jfrmw1.PD7 (VSYS_GPU), Jfrmw1.PD8 (VSYS_GPU), Jfrmw1.PE7 (VSYS_GPU), Jfrmw1.PE8 (VSYS_GPU), Jfrmw1.PF7 (VSYS_GPU), Jfrmw1.PF8 (VSYS_GPU), Jfrmw1.PG7 (VSYS_GPU), Jfrmw1.PG8 (VSYS_GPU)
WAKE#: Jmxm1.4 (WAKE#)
dock_USB1_D+: Jdock1.66 (USB2_D+), U1.11 (DP1)
dock_USB1_D-: Jdock1.68 (USB2_D-), U1.10 (DM1)
dock_USB2_D+: Jdock1.72 (USB3_D+), U1.9 (DP2)
dock_USB2_D-: Jdock1.74 (USB3_D-), U1.8 (DM2)
frmw_USB_D+: Jfrmw1.PJ3 (USB+), U1.16 (DPU)
frmw_USB_D-: Jfrmw1.PK3 (USB-), U1.15 (DMU)
rp2040_USB_D+: U1.7 (DP3), U2.47 (USB_DP)
rp2040_USB_D-: U1.6 (DM3), U2.46 (USB_DM)
typeC_USB_D+: J1.A6 (D+), J1.B6 (D+), U1.5 (DP4)
typeC_USB_D-: J1.A7 (D-), J1.B7 (D-), U1.4 (DM4)

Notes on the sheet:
place cap close to gate pins
why doesn't the expansion bay have USB 3.0 SMH
Funny DP++ HDMI DDC stuff MXM DP B / Dock DP 1
Funny DP++ HDMI DDC stuff MXM DP D / Dock DP 2
Power connections
from gpu
to port
Transistors for bypassing caps
Dongle detection input pin to bypass transistor control
TODO: somehow switch on/off the ALW rails
TODO: DP HPD shenanigens

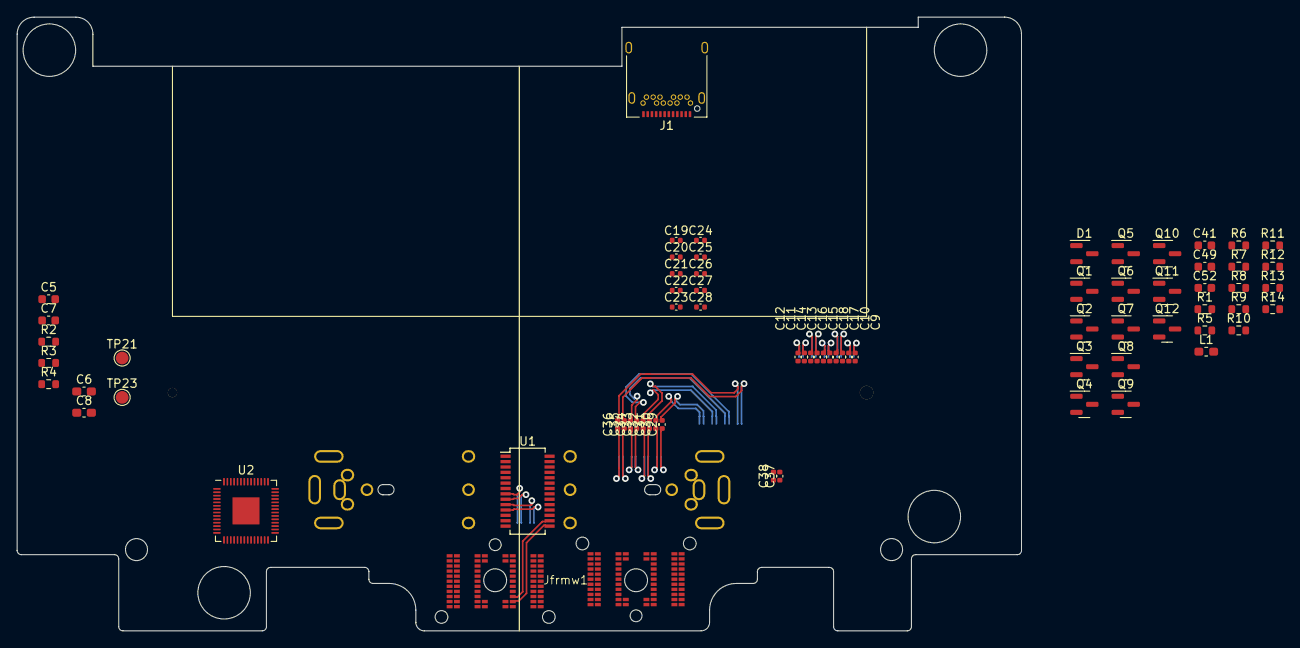
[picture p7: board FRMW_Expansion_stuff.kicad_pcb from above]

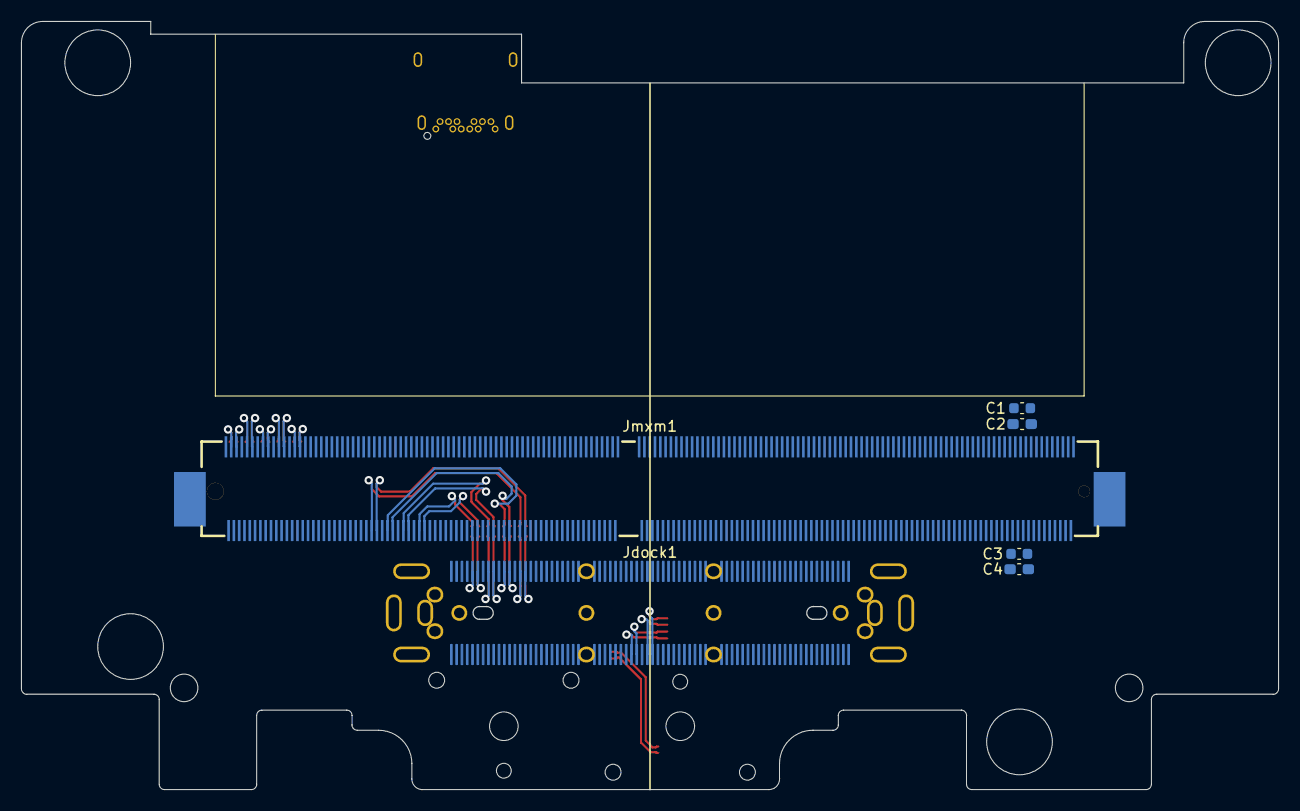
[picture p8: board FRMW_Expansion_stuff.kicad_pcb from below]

Board: 2 copper layers, 118.7 x 72.5 mm, 77 parts (6 on the bottom side), 153 nets.

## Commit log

2024-04-16 The files
    [ExpansionBay.kicad_pcb, FRMW_Expansion_stuff.kicad_pcb, FRMW_Expansion_stuff.kicad_sch]
2025-03-22 added 3d model for dock port
    don't tell JAE I put the model online lol
    [FRMW_Expansion_stuff.kicad_pcb]
